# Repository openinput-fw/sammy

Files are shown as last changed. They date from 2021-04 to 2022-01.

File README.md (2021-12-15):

# sammy



[](https://github.com/openinput-fw)

Open source wired mouse hardware.

The little brother of [big-sammy](https://github.com/openinput-fw/big-sammy).

Please see the [documentation](https://sammy.readthedocs.io/en/latest)
for more information.

## Specifications
- 8 kHz sampling rate support
- Zero latency switch debounce
- Onboard configuration memory
- 2 main mouse buttons (satellite* configuration for both)
- 2 side buttons (symmetric to allow easy left/right handedness)
- encoder + wheel button (satellite* configuration)
- RGB Led

`*meaning, a separate board from the core with the controller and sensor`

## Firmware

*sammy* is meant to run on [openinput](https://github.com/openinput-fw/openinput).

## License

This hardware is licensed under the [CERN-OHL-P v2](LICENSE) license.

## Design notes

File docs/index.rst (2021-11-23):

:hide-toc:

*****
sammy
*****
*sammy* is an open source wired mouse hardware implementation.

The little brother of big-sammy_

State of the project
====================

First prototype under testing, barebones firmware support for openinput_ under development.

.. admonition:: Roadmap

   - Initial design |:+1:|
   - First prototype manufactured and assembled |:+1:|
   - Tinyusb driver support |:hammer:|
   - Barebones firmware support |:hammer:|
   - Documentation |:hammer:|
   - Hardware improvements
   - First release

   ========== ================
   |:+1:|     Done!
   |:hammer:| Work in progress
   ========== ================

Specifications
==============

* 8 kHz sampling rate support
* Zero latency switch debounce
* Onboard configuration memory
* 2 main mouse buttons (satellite* configuration for both)
* 2 side buttons (symmetric to allow easy left/right handedness)
* encoder + wheel button (satellite* configuration)
* RGB Led

Hardware
========

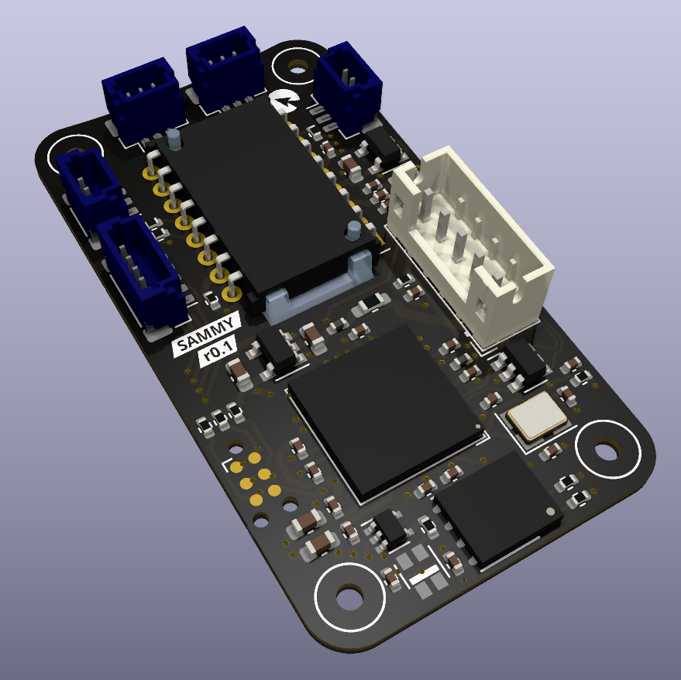
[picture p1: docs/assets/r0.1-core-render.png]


* ATSAM3U MCU (ATSAM3UxC)
* Optical sensor [PMW3330, PMW3360, PMW3389, Truemove3]
* onboard conectors:
   * JST PH (2mm pitch) for USB
   * JST SH (1mm pitch) for stellite boards
* M2 mounting hardware

+--------------+
| USB   pinout |
+-----+--------+
| pin | func   |
+=====+========+
| 1 	| VCC    |
+-----+--------+
| 2 	| DM     |
+-----+--------+
| 3 	| DP     |
+-----+--------+
| 4 	| GND    |
+-----+--------+
| 5 	| Shield |
+-----+--------+

Peripheral boards are used for the buttons and encoder, available at generic-mouse-boards.

.. toctree::
   :caption: External Links
   :hidden:

   Source <https://github.com/openinput-fw/sammy>
   Firmware <https://openinput.readthedocs.io>
   Issue Tracker <https://github.com/openinput-fw/sammy/issues>

.. _big-sammy: https://big-sammy.readthedocs.io
.. _openinput: https://openinput.readthedocs.io

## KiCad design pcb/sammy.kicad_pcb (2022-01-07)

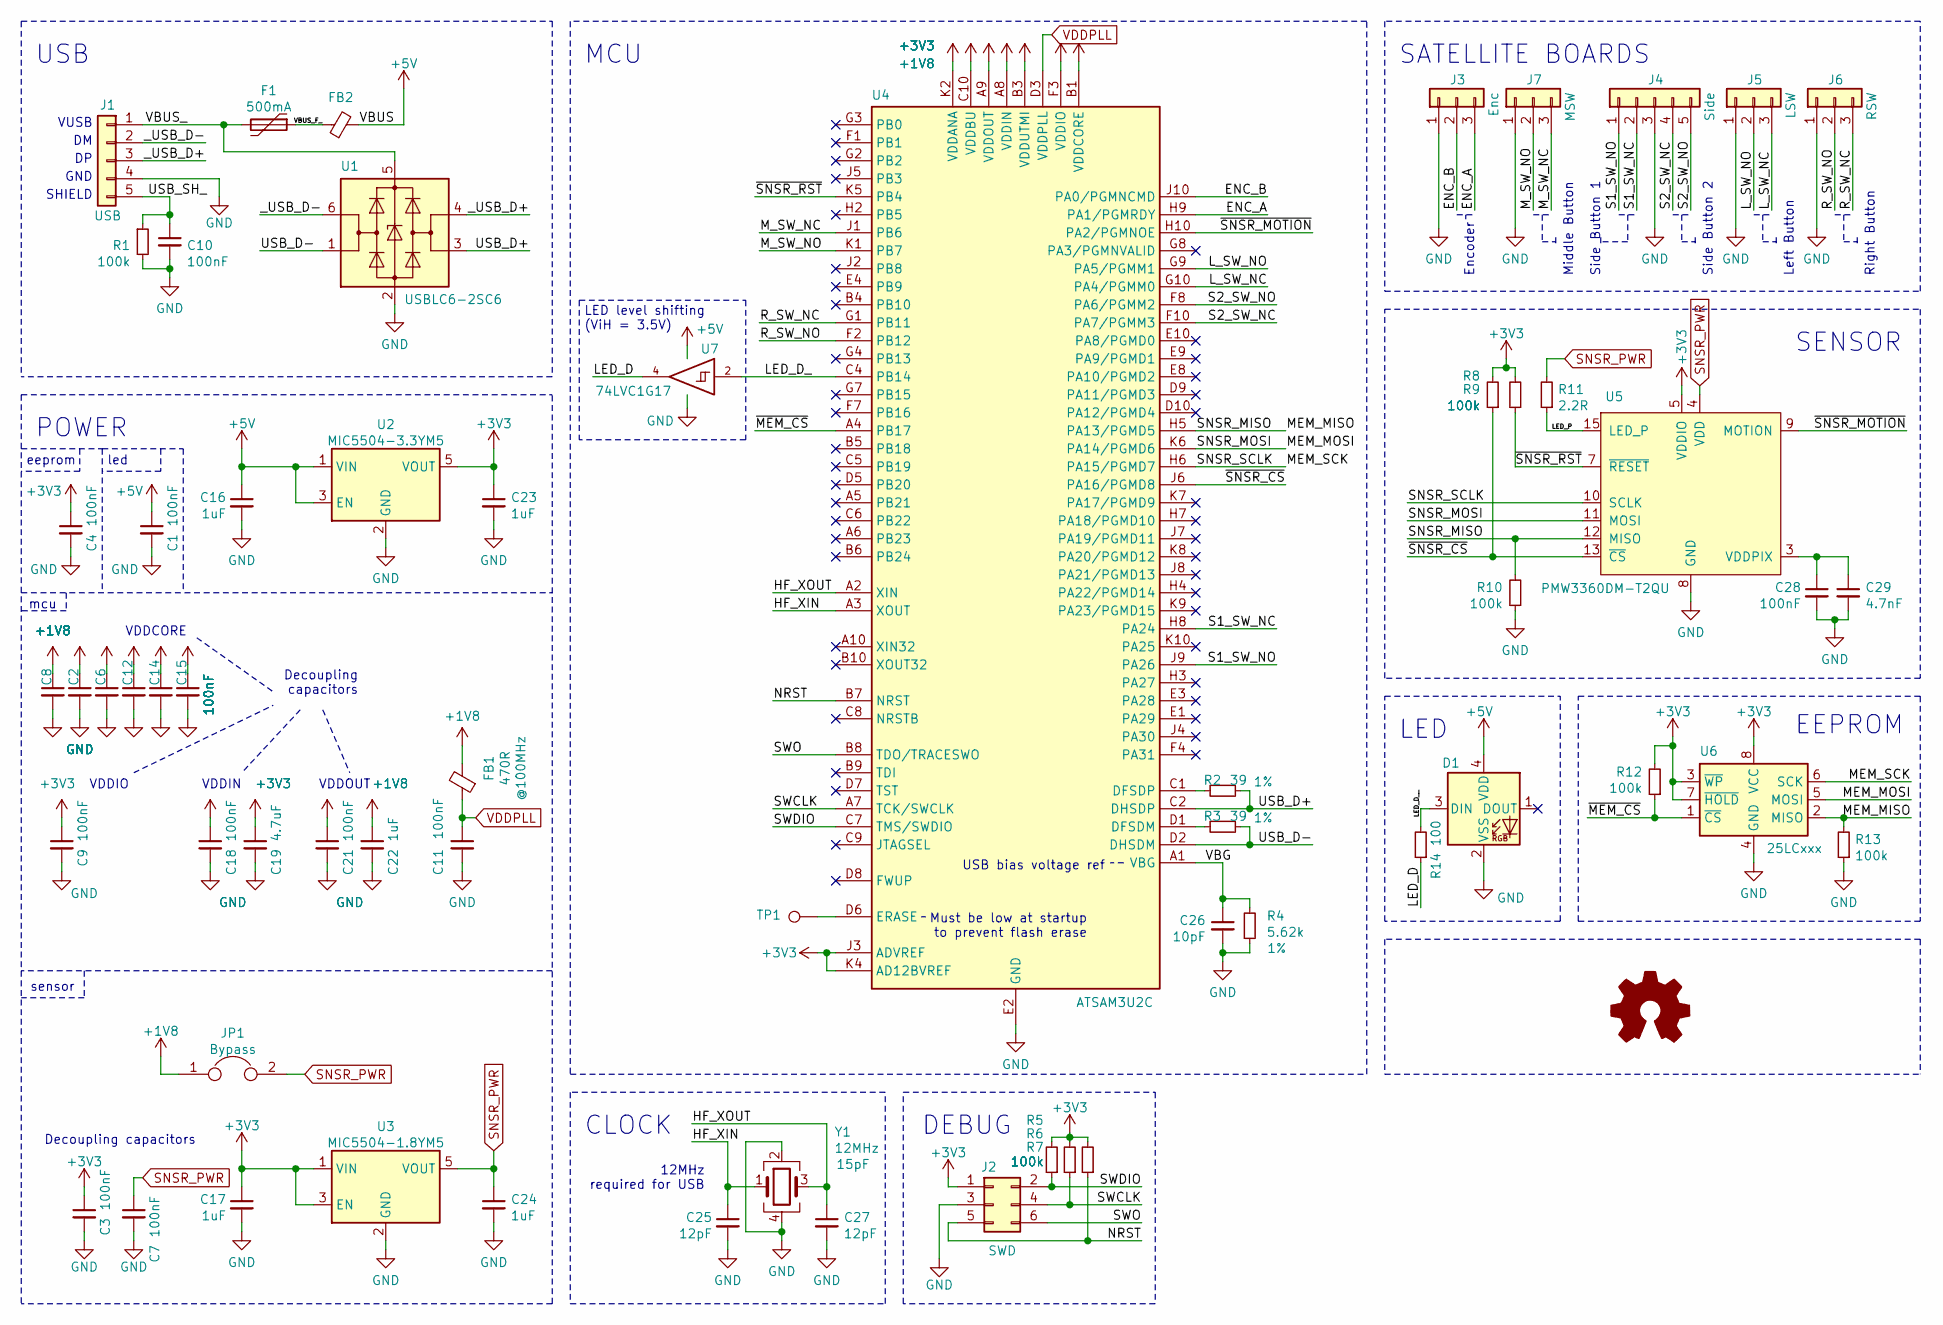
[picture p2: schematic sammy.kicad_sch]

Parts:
C1, C2, C3, C4, C6, C7, C8, C9, C10, C11, C12, C14, C15, C18, C21, C28: 100nF; C_0402_1005Metric
C16, C17, C22, C23, C24: 1uF; C_0603_1608Metric
C19: 4.7uF; C_0603_1608Metric
C25, C27: 12pF; C_0402_1005Metric
C26: 10pF; C_0402_1005Metric
C29: 4.7nF; C_0402_1005Metric
D1: ws2812-2020
F1: 500mA; Fuse_0603_1608Metric_Castellated
FB1: 470R; L_0402_1005Metric
FB2: L_0402_1005Metric
J1: USB; JST_PH_B5B-PH-K_1x05_P2.00mm_Vertical
J2: SWD; Tag-Connect_TC2030-IDC-NL_2x03_P1.27mm_Vertical
J3: Enc; JST_SH_BM03B-SRSS-TB_1x03-1MP_P1.00mm_Vertical
J4: Side; JST_SH_BM05B-SRSS-TB_1x05-1MP_P1.00mm_Vertical
J5: LSW; JST_SH_BM03B-SRSS-TB_1x03-1MP_P1.00mm_Vertical
J6: RSW; JST_SH_BM03B-SRSS-TB_1x03-1MP_P1.00mm_Vertical
J7: MSW; JST_SH_BM03B-SRSS-TB_1x03-1MP_P1.00mm_Vertical
JP1: Bypass; SolderJumper-2_P1.3mm_Open_RoundedPad1.0x1.5mm
R1, R5, R6, R7, R8, R9, R10, R12, R13: 100k; R_0402_1005Metric
R2, R3: 39; R_0402_1005Metric; Tolerance 1%
R4: 5.62k; R_0402_1005Metric; Tolerance 1%
R11: 2.2R; R_0402_1005Metric
R14: 100; R_0402_1005Metric
TP1: TestPoint_Pad_D1.0mm
U1: USBLC6-2SC6; SOT-23-6
U2: MIC5504-3.3YM5; SOT-23-5
U3: MIC5504-1.8YM5; SOT-23-5
U4: ATSAM3U2C; TFBGA-100_9.0x9.0mm_Layout10x10_P0.8mm
U5: PMW3360DM-T2QU; PMW3360
U6: 25LCxxx; DFN-S-8-1EP_6x5mm_P1.27mm
U7: 74LVC1G17; SOT-353_SC-70-5
Y1: 12MHz; Crystal_SMD_3225-4Pin_3.2x2.5mm

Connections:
+1V8: C2.1, C6.1, C8.1, C12.1, C14.1, C15.1, C21.1, C22.1, FB1.2, JP1.1, U4.A9 (VDDOUT), U4.B1 (VDDCORE), U4.D4 (VDDCORE), U4.E7 (VDDCORE), U4.F9 (VDDCORE), U4.G5 (VDDCORE), U4.H1 (VDDCORE)
+3V3: C3.1, C4.1, C9.1, C17.1, C18.1, C19.1, C23.1, J2.1, R5.2, R6.2, R7.2, R8.2, R9.2, R12.2, U2.5 (VOUT), U3.1 (VIN), U3.3 (EN), U4.A8 (VDDIN), U4.B3 (VDDUTMI), U4.C10 (VDDBU), U4.E6 (VDDIO), U4.F3 (VDDIO), U4.F5 (VDDIO), U4.J3 (ADVREF), U4.K2 (VDDANA), U4.K4 (AD12BVREF), U5.5 (VDDIO), U6.3 (~WP), U6.7 (~HOLD), U6.8 (VCC)
+5V: C1.1, C16.1, D1.4 (VDD), FB2.2, U2.1 (VIN), U2.3 (EN), U7.5 (VCC)
/ENC_A: J3.3, U4.H9 (PA1/PGMRDY)
/ENC_B: J3.2, U4.J10 (PA0/PGMNCMD)
/HF_XIN: C25.1, U4.A3 (XOUT), Y1.1
/HF_XOUT: C27.1, U4.A2 (XIN), Y1.3
/LED_D: R14.1, U7.4
/LED_D_: U4.C4 (PB14), U7.2
/LED_D__: D1.3 (DIN), R14.2
/LED_P: R11.1, U5.15 (LED_P)
/L_SW_NC: J5.3, U4.G10 (PA4/PGMM0)
/L_SW_NO: J5.2, U4.G9 (PA5/PGMM1)
/MEM_MISO: R10.2, R13.2, U4.H5 (PA13/PGMD5), U5.12 (MISO), U6.2 (MISO)
/MEM_MOSI: U4.K6 (PA14/PGMD6), U5.11 (MOSI), U6.5 (MOSI)
/MEM_SCK: U4.H6 (PA15/PGMD7), U5.10 (SCLK), U6.6 (SCK)
/M_SW_NC: J7.3, U4.J1 (PB6)
/M_SW_NO: J7.2, U4.K1 (PB7)
/NRST: J2.5, R7.1, U4.B7 (NRST)
/R_SW_NC: J6.3, U4.G1 (PB11)
/R_SW_NO: J6.2, U4.F2 (PB12)
/S1_SW_NC: J4.2, U4.H8 (PA24)
/S1_SW_NO: J4.1, U4.J9 (PA26)
/S2_SW_NC: J4.4, U4.F10 (PA7/PGMM3)
/S2_SW_NO: J4.5, U4.F8 (PA6/PGMM2)
/SWCLK: J2.4, R6.1, U4.A7 (TCK/SWCLK)
/SWDIO: J2.2, R5.1, U4.C7 (TMS/SWDIO)
/SWO: J2.6, U4.B8 (TDO/TRACESWO)
/USB_D+: R2.1, U1.3 (I/O2), U4.C2 (DHSDP)
/USB_D-: R3.1, U1.1 (I/O1), U4.D2 (DHSDM)
/USB_SH_: C10.1, J1.5, R1.1
/VBG: C26.1, R4.2, U4.A1 (VBG)
/VBUS_: F1.2, J1.1, U1.5 (VBUS)
/VBUS_F_: F1.1, FB2.1
/_USB_D+: J1.3, U1.4 (I/O2)
/_USB_D-: J1.2, U1.6 (I/O1)
/~MEM_CS: R12.1, U4.A4 (PB17), U6.1 (~CS)
/~SNSR_CS: R8.1, U4.J6 (PA16/PGMD8), U5.13 (~CS)
/~SNSR_MOTION: U4.H10 (PA2/PGMNOE), U5.9 (MOTION)
/~SNSR_RST: R9.1, U4.K5 (PB4), U5.7 (~RESET)
GND: C1.2, C2.2, C3.2, C4.2, C6.2, C7.2, C8.2, C9.2, C10.2, C11.2, C12.2, C14.2, C15.2, C16.2, C17.2, C18.2, C19.2, C21.2, C22.2, C23.2, C24.2, C25.2, C26.2, C27.2, C28.2, C29.2, D1.2 (VSS), J1.4, J2.3, J3.1, J4.3, J5.1, J6.1, J7.1, R1.2, R4.1, R10.1, R13.1, U1.2 (GND), U2.2 (GND), U3.2 (GND), U4.B2 (GNDUTMI), U4.C3 (GNDPLL), U4.E2 (GND), U4.E5 (GNDBU), U4.F6 (GND), U4.G6 (GND), U4.K3 (GNDANA), U5.8 (GND), U6.4 (GND), U7.3 (GND), Y1.2, Y1.4
unnamed: C28.1, C29.1, U5.3 (VDDPIX)
unnamed: TP1.1, U4.D6 (ERASE)
unnamed: R2.2, U4.C1 (DFSDP)
unnamed: R3.2, U4.D1 (DFSDM)
SNSR_PWR: C7.1, C24.1, JP1.2, R11.2, U3.5 (VOUT), U5.4 (VDD)
VDDPLL: C11.1, FB1.1, U4.D3 (VDDPLL)

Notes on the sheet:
Side Button 2
Left Button
DEBUG
USB
CLOCK
SENSOR
USB bias voltage ref
VDDCORE
SHIELD
Right Button
VUSB
led
MCU
12MHz required for USB
mcu
Decoupling capacitors
Side Button 1
GND
POWER
sensor
Encoder
Middle Button
eeprom
SATELLITE BOARDS
Decoupling capacitors
VDDIO
LED
LED level shifting (ViH = 3.5V)
VDDIN
Must be low at startup to prevent flash erase
EEPROM
VDDOUT

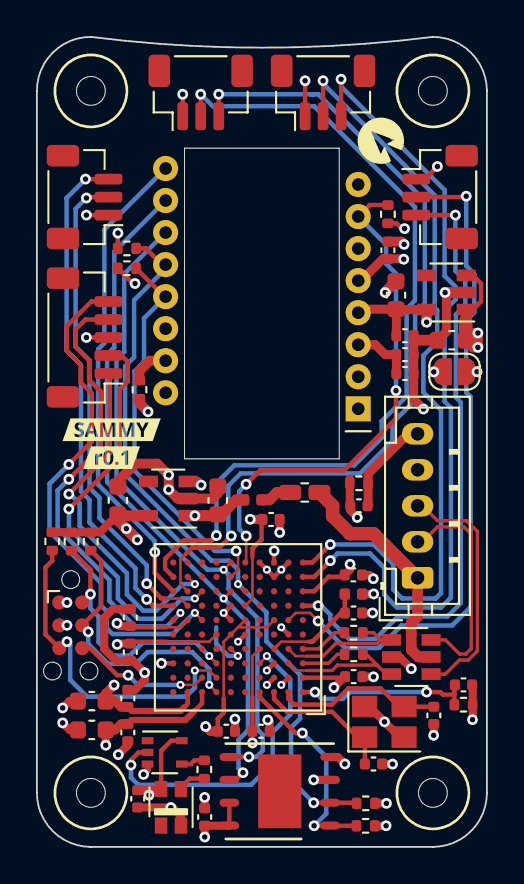
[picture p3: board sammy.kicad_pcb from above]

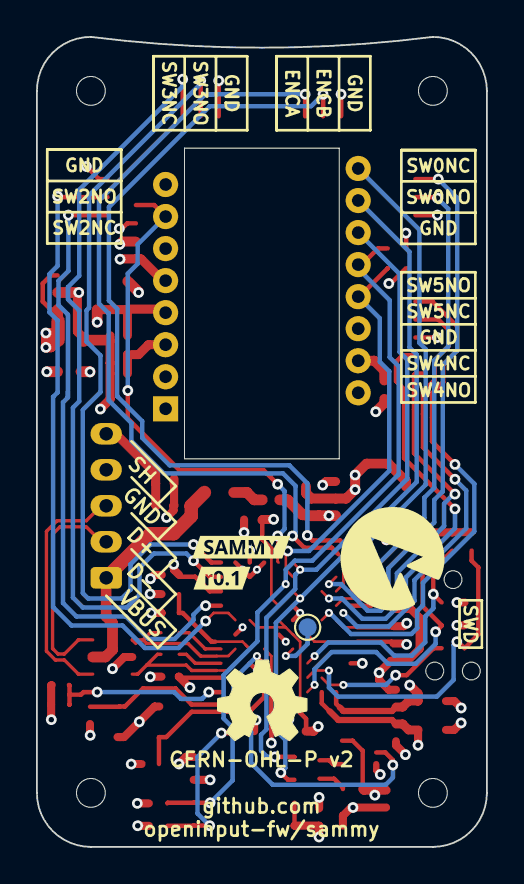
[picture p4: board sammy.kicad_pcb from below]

Board: 4 copper layers, 25.0 x 45.0 mm, 65 parts (3 on the bottom side), 47 nets.

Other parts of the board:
svg2mod, svg2mod#2, svg2mod#3, svg2mod#4: G***; svg2mod

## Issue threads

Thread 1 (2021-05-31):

Connection to the usb peripheral is not correct

perigoso, 2021-05-31:
current r0.0 does not connect the usb ls pins, which are required, only the hs.

fix:
connect usb ls pins through 39 ohm resistors to the usb data lines

Closed 2021-06-07.

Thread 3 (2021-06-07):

Consider changing RGB led from addressable LED to regular RGB LED

perigoso, 2021-06-07:
In r0.1 we used a addressable LED for the RGB LED, this doesn't make immediate sense because its a single LED, but this needs only one line to drive, and in the end its more compact (if we wanted to take advantage of 5v for a regular led)

I'm considering going with a regular LED, but there's not enough space for a regular led using the 5v, because the ios are not 5v tolerant and would require 3 transistors, alternative solution is a 74LVC3G17 (3 gate schmitt trigger) as a level shifter, or we could go with direct drive. The reason 5v drives is prefereable to direct drive is that blue and green leds usually have high forward voltages (3.2 - 3.4V), and driving them with 3.3V will result in a weak color range (harder to achieve white for instance)

one other reason to consider keeping the addressable led is the ability to add extra leds by the user (we need to add a easier way to connect to it though, like some edge pads)

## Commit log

2021-04-27 kicad: add local libraries (copy from big-sammy + atsam3u)
2021-04-27 pcb: r0.1 schematic and layout based on big-sammy
    [core.kicad_pcb, core.kicad_sch]
2021-04-27 pcb: document label creation
2021-04-27 pcb: change minimum via diameter to 0.45mm
    [core.kicad_pcb]
2021-04-30 pcb: move kicad project
    [sammy.kicad_pcb, sammy.kicad_sch]
2021-04-30 kicad: removed unused libs
2021-06-07 fix #2: typo in link to source
    [sammy.kicad_pcb]
2021-06-07 fix #1: Connection to the usb peripheral is not correct
    [sammy.kicad_pcb, sammy.kicad_sch]
2021-07-02 readme: add peripheral board reference
2022-01-07 kicad: save pcb with v6.0
    [sammy.kicad_pcb, sammy.kicad_sch]

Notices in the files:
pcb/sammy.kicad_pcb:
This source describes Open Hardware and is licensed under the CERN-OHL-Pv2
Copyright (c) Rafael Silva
